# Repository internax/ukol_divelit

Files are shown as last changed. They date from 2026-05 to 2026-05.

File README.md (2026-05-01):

# SPI FLASH programátor
Tento repozitář obsahuje souboru k návrhu SPI Flash programátoru.

## Struktura
- Výrobní soubory jsou v adresáři: programator_spi/production/programator_spi.zip
- Schéma je dostupné v adresáři: programator_spi/schema_pdf/programator_spi.pdf
# Návrhová rozhodnutí

## Patice pro DIP8

Původní záměr byl použít ZIF socket, ten se však pro pDIP8 pouzdro prakticky nevyrábí. Zvolil jsem proto přesnou patici z doporučených komponent. Klíčovými kritérii byl nízký odpor kontaktů a zlaté pokovení pinů. Životnost patice je dle dokumentace přibližně 500 cyklů, což by pro daný účel mělo být dostatečné. Pokud by se požadavky na počet cyklů zvýšily, bylo by nutné přejít na ZIF patici většího formátu.

## USB rozhraní

Nejprve jsem navrhl USB rozhraní. Použil jsem ESD ochranu z doporučených komponent. Zvažoval jsem ještě ECMF02-2AMX6, která nabízí common mode ochranu a je použita například v referenčním designu MB1801.

Dále jsem přidal proudovou ochranu — polyfuse. Maximální proud jsem stanovil takto: flash paměť odebírá při zápisu až 30 mA, MCU pak dle datasheetu až 150 mA. Zvolil jsem proto polyfuse 200 mA, která poskytuje rozumnou rezervu; v případě potřeby ji lze snadno vyměnit.

Dle specifikace jsem na linku D+ přidal pull-up rezistor 1k5Ω.

## MCU

S STM32 jsem dosud nenavrhoval, proto jsem si stáhl AN a postupoval podle ní. Jako první jsem řešil napájení — přidal jsem blokovací kondenzátory na příslušné piny. Oddělení napájení analogové části jsem neřešil, protože zde nemá smysl.

Vybral jsem krystal 8 MHz tak, aby byl splněn margin, a navrhl jsem kondenzátory s tím, že Cp uvažuji jako 5 pF. Margin jsem ověřil dle AN2867 — vychází gm = 26,4 mA/V, rezerva je dostatečná.

## Programovací rozhraní

Pokračoval jsem programovacím rozhraním. Zvolil jsem SWD s výstupem SWO, konektor Tag-Connect.

## Tlačítka

Přidal jsem tlačítko RESET, protože je vhodné ho mít vždy vyvedené, a tlačítko BOOT pro změnu bootovacího režimu, například pro DFU přes USB. Tlačítko ERASE ani FLASH není zmíněno v zadání, takže jsem je nepřidával — zbytečná komplexita.

## Indikace

Pro indikaci stavu jsem zvolil adresovatelnou LED, která funguje s 5V logikou. Teoreticky by byl potřeba level shifter, nicméně v praxi funguje spolehlivě i bez něj, zejména na malých vzdálenostech.

## Flash

K napájení jsem přidal 100 nF kondenzátor, SPI jsem připojil k MCU, /WP a /HOLD jsem vyvedl na VDD, protože ani jednu z funkcí nepotřebuji. Na piny sdílené s MCU jsem přidal ESD ochranu.

## Test pady
Přidávám testpady s dírou uprostřed, protože v nich líp drží probe osciloskopu a ve dvouvrstvé desce ničemu nevadí.

*Text Návrhová rozhodnutí byl upravenu pomocí generativní umělé inteligence, originál je dostupný v: original_notes/notes.txt*

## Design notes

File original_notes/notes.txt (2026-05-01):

- Použiji doporučený čip s USB rozhraním, protože jej nativně podporuje
- Chtěl jsem použít ZFI socket,a le pro pDIP8 se moc nevyrábí takže použiju něco jiného s důrazem na to aby sto vyrželo opakované vysouvání a zasouvání čipů
- Existují přesné patice, které by tohle měly zaručit
- Vybírám patci ze zadání protože má nízký odpor kontaktů a zalté pokovení. Má životnost cca 500 cyklů [DIP IC Sockets](https://www.petervis.com/electronics/DIP_IC_Sockets/IC_Sockets.html) pokud by bylo potřeba víc musle by se použít větší ZIF
- Zbytek komponent jsem taky použil z doporučených
# USB
- Prvně navrhuji USB interface. Použiju ESD ze zadání. Pokud bych neměl doporučené komponenty,  bych zvažoval použití **ECMF02-2AMX6** která má common mode ochranu a je použita například v MB1801 u USB interface.
- Přidám produovou ochranu - polyfuse
	musím si určit max porud:
	- Paměť má největši spotřebu při zápisu - 30 mA
	- STM zvládne dle datasheetu 150 mA
	Takže polyfuse 200 mA by mohla být ok, kdyžtak se vymění
- dle specifikace přidávám 1k5 odpor na dp
# MCU
- S stm jsem nikdy nenavrhoval takže si stáhu AN a jedu podle ní. Jako první řeším napájení. 
	připojím decoupling kapacitory tam kam patří. odděelní napájení analogové části neřeším, protože to tady nemá cenu
- vybírám krystal na 8 MHz tak aby by splněn margin a navrhuji kondenzátory s tím že Cp beru jako 5pF
- Počítám si margin podle AN2867 a zjišťuji že je oka a mám dostatečnou rezervu gm=26,4 mA/V
# debug
- pokračuji, programovacím rozhraním. Volím rozhraní swo konektor tag connect
# Tlačítka
- potřebuji tlačítko pro reset, uvažuji nad tlačítkem erase a flash ale není zmíněno v zadání tak nebudu zbytečně přidávat komplexitu
- tlačítko reset přidávám protože je vhodné ho mít vyvedené a boot pro změnu bootovacího režimu např z usb
# Indikace
Pro indikaci stavu jsem vybral adresovatelnoou diodu, která funguje s 5V logikou, teoreticky by měl být level shifter, nicméně v praxi funguje dobře zeména na malé vzdálenosti i bez level shifteru.

# Flash
zbývá připojit flash paměť. k napájení přidám 100nF, připojím spi do čipu a WP a hold na vdd, protože ani jednu z funkcí nepotřebuji, přidám esd ochranu na piny které jsou spojeny s MCU

# Test pady
Přidávám testpady s dírou uprostřed, protože v nich líp drří probe osciloskopu a ve dvouvrstvé desce ničemu nevadí

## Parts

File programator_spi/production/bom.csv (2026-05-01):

Designator | Footprint | Quantity | Value | LCSC Part #
3V3, 5V, CS, MISO, MOSI, SCK | TestPoint_THTPad_D1.0mm_Drill0.5mm | 6 | TestPoint
C1, C4, C5 | 0603 | 3 | 10u
C10 | 0603 | 1 | 1u
C11, C12, C15, C2, C3, C6, C7, C8, C9 | 0603 | 9 | 100n
C13, C14 | 0603 | 2 | 27p
CR1 | SOT-223-3_TabPin2 | 1 | LD1117S33CTR
D1 | SOD2512X110N | 1 | D_Schottky
D2 | LED_WS2812B-Mini_PLCC4_3.5x3.5mm | 1 | WS2812B
F1 | 1206 | 1 | Polyfuse
H2, H3 | MountingHole_3.5mm | 2 | MountingHole
IC1 | DIP-8_W7.62mm_Socket | 1 | SST25VF080B-50-4C-PAE
J1 | USB4105_GCT | 1 | USB4105-GF-A
R1, R2 | 0603 | 2 | 5k1
R3, R4, R5 | 0603 | 3 | 10k
R7 | 0603 | 1 | 1k5
S1, S2 | TL3365AF250QG | 2 | TL3365AF180QG
U1 | LQFP48_STM-M | 1 | STM32F103C8T6
U2 | SOT-23-6 | 1 | USBLC6-4SC6
U3 | SOT-23-6 | 1 | USBLC6-2SC6
Y2 | LFXTAL055663Reel | 1 | 8MHz

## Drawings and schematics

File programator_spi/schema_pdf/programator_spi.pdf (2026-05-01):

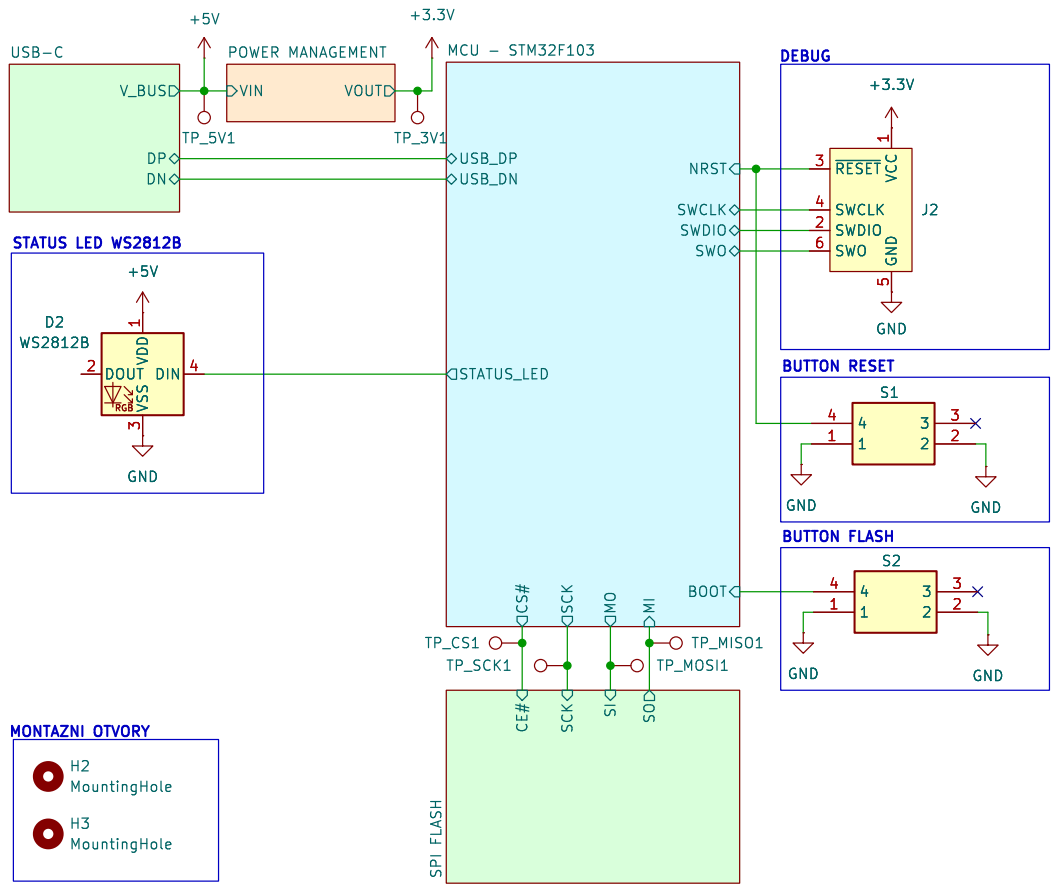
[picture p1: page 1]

5 ~{RESET} 3 SWCLK 4 SWDIO 2 SWO 6

5 ~{RESET} 3 SWCLK 4 SWDIO 2 SWO 6 GND

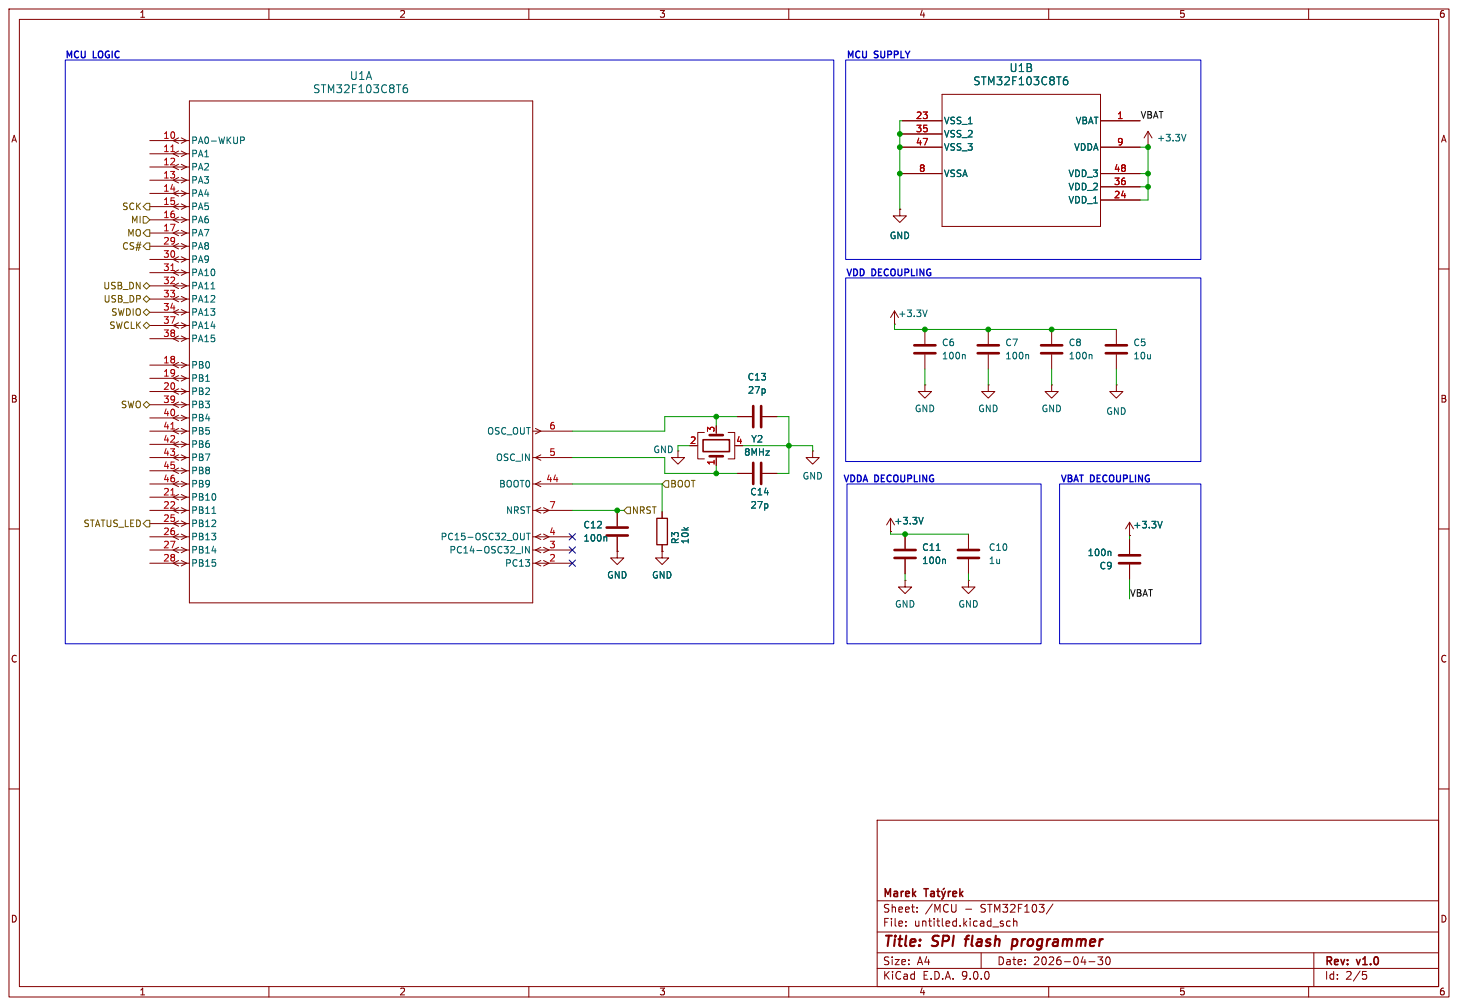
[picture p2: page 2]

CS# SCK MOMI SWO

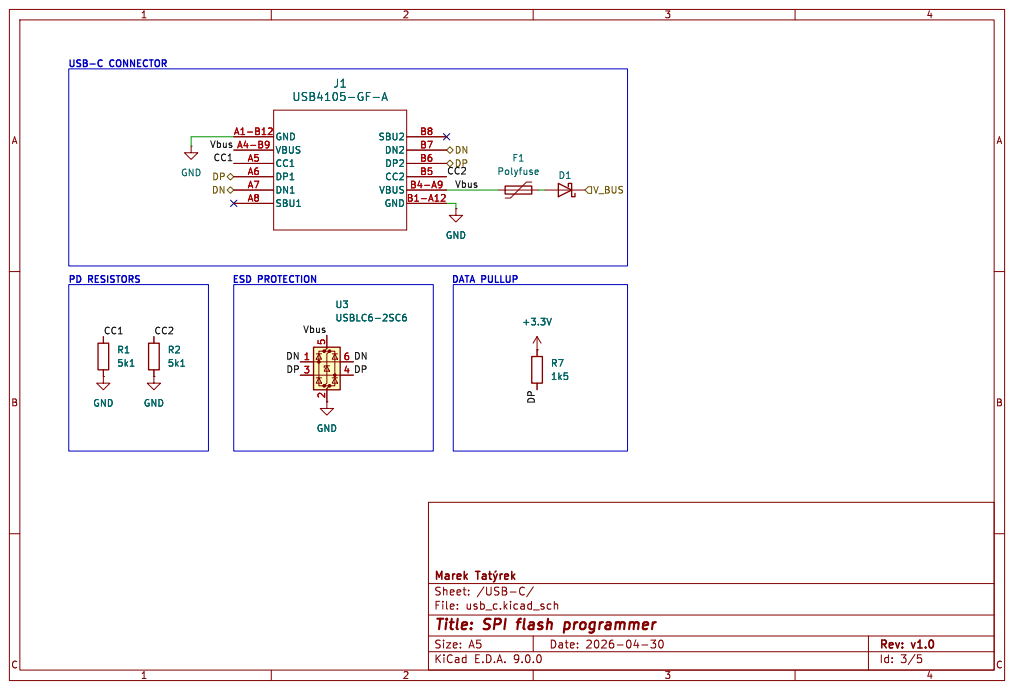
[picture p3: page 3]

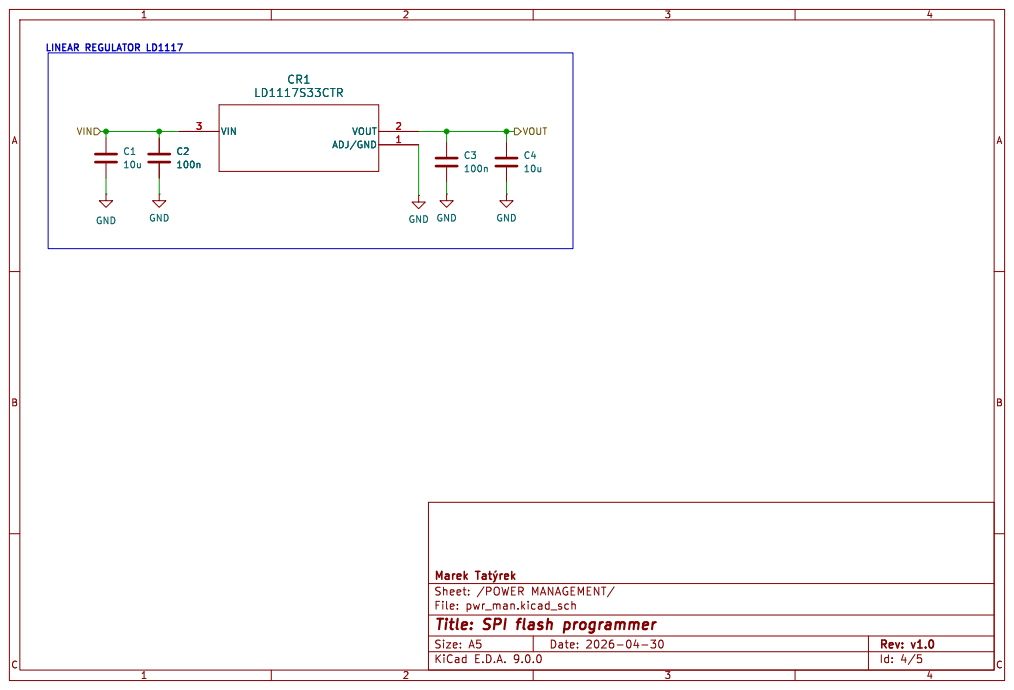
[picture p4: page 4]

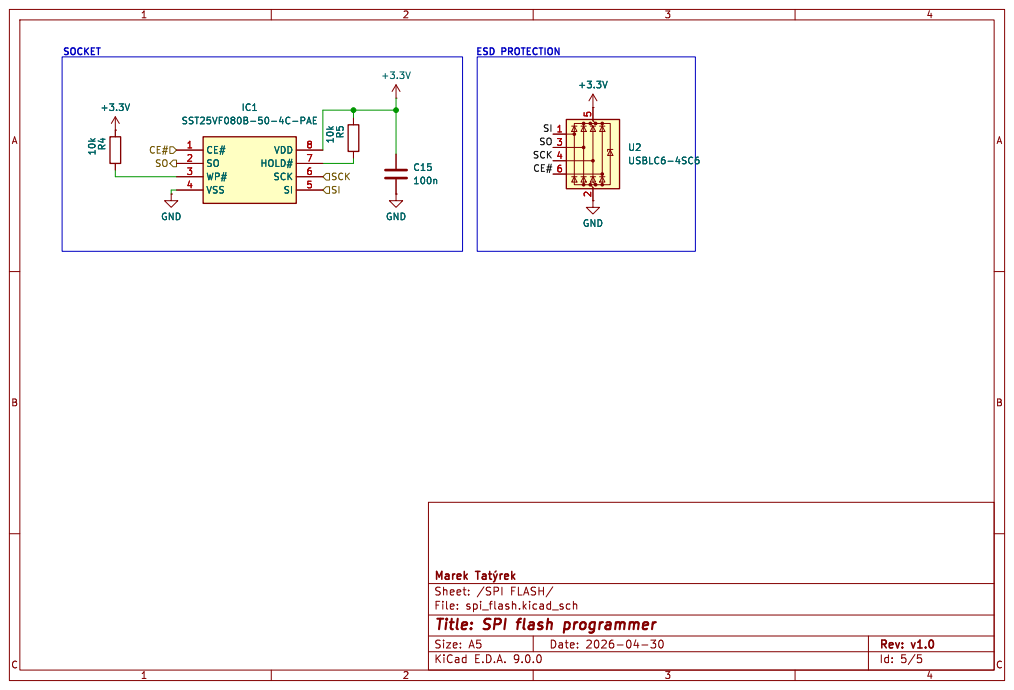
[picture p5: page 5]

5 2 U2 USBLC6-4SC6 CE# 1 SO 2 WP# 3 VSS 4 VDD 8 HOLD# 7 SCK 6 SI 5

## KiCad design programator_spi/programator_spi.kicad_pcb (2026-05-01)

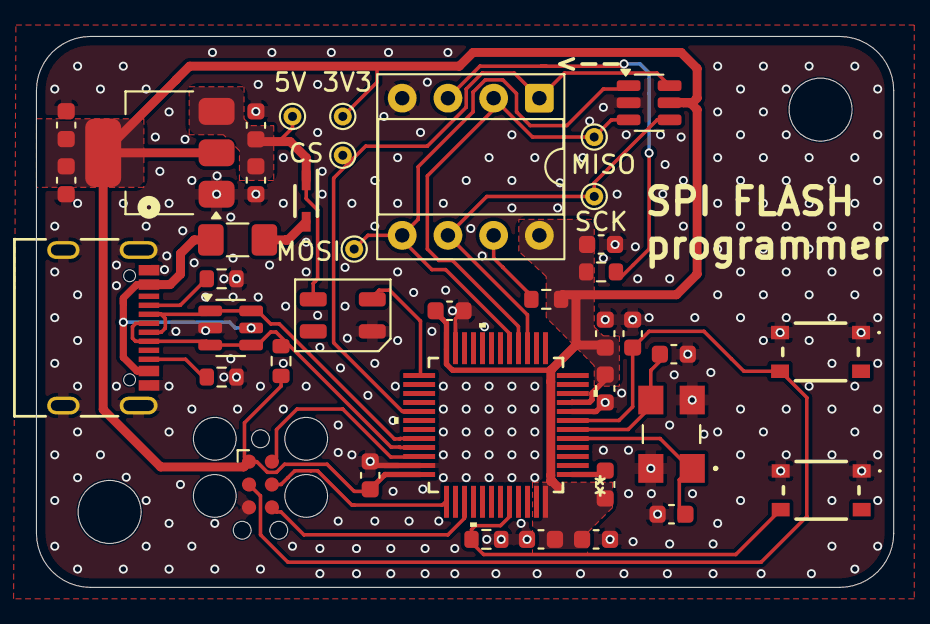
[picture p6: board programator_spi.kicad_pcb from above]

Board: 2 copper layers, 47.6 x 30.6 mm, 42 parts (0 on the bottom side), 24 nets.

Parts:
3V3, 5V: TestPoint; TestPoint_THTPad_D1.0mm_Drill0.5mm
C1, C4, C5: 10u; C_0603_1608Metric
C2, C3, C6, C7, C8, C9, C11, C12, C15: 100n; C_0603_1608Metric
C10: 1u; C_0603_1608Metric
C13, C14: 27p; C_0603_1608Metric
CR1: LD1117S33CTR; SOT-223-3_TabPin2
CS: TestPoint; TestPoint_THTPad_D1.0mm_Drill0.5mm
D1: D_Schottky; SOD2512X110N
D2: WS2812B; LED_WS2812B-Mini_PLCC4_3.5x3.5mm
F1: Polyfuse; Fuse_1206_3216Metric_Pad1.42x1.75mm_HandSolder
H2, H3: MountingHole; MountingHole_3.5mm
IC1: SST25VF080B-50-4C-PAE; DIP-8_W7.62mm_Socket
J1: USB4105-GF-A; USB4105_GCT
J2: Conn_ARM_SWD_TagConnect_TC2030; Tag-Connect_TC2030-IDC-FP_2x03_P1.27mm_Vertical
MISO: TestPoint; TestPoint_THTPad_D1.0mm_Drill0.5mm
MOSI: TestPoint; TestPoint_THTPad_D1.0mm_Drill0.5mm
R1, R2: 5k1; R_0603_1608Metric
R3, R4, R5: 10k; R_0603_1608Metric
R7: 1k5; R_0603_1608Metric
S1, S2: TL3365AF180QG; TL3365AF250QG
SCK: TestPoint; TestPoint_THTPad_D1.0mm_Drill0.5mm
U1: STM32F103C8T6; LQFP48_STM-M
U2: USBLC6-4SC6; SOT-23-6
U3: USBLC6-2SC6; SOT-23-6
Y2: 8MHz; LFXTAL055663Reel

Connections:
+3.3V: 3V3.1, C3.2, C4.2, C5.2, C6.2, C7.2, C8.2, C9.1, C10.1, C11.2, C15.2, CR1.2 (VOUT), IC1.8 (VDD), J2.1 (VCC), R4.2, R5.2, R7.1, U1.9 (VDDA), U1.24 (VDD_1), U1.36 (VDD_2), U1.48 (VDD_3), U2.5 (VBUS)
+5V: 5V.1, C1.2, C2.2, CR1.3 (VIN), D1.1 (K), D2.1 (VDD)
/MCU - STM32F103/BOOT: R3.1, S2.4, U1.44 (BOOT0)
/MCU - STM32F103/NRST: C12.2, J2.3 (~RESET), S1.4, U1.7 (NRST)
/MCU - STM32F103/STATUS_LED: D2.4 (DIN), U1.25 (PB12)
/MCU - STM32F103/SWCLK: J2.4 (SWCLK), U1.37 (PA14)
/MCU - STM32F103/SWDIO: J2.2 (SWDIO), U1.34 (PA13)
/MCU - STM32F103/SWO: J2.6 (SWO), U1.39 (PB3)
/MCU - STM32F103/VBAT: C9.2, U1.1 (VBAT)
/SPI FLASH/CE#: CS.1, IC1.1 (CE#), U1.29 (PA8), U2.6 (I/O4)
/SPI FLASH/SCK: IC1.6 (SCK), SCK.1, U1.15 (PA5), U2.4 (I/O3)
/SPI FLASH/SI: IC1.5 (SI), MOSI.1, U1.17 (PA7), U2.1 (I/O1)
/SPI FLASH/SO: IC1.2 (SO), MISO.1, U1.16 (PA6), U2.3 (I/O2)
/USB-C/CC1: J1.A5 (CC1), R1.1
/USB-C/CC2: J1.B5 (CC2), R2.1
/USB-C/DN: J1.A7 (DN1), J1.B7 (DN2), U1.32 (PA11), U3.1 (I/O1), U3.6 (I/O1)
/USB-C/DP: J1.A6 (DP1), J1.B6 (DP2), R7.2, U1.33 (PA12), U3.3 (I/O2), U3.4 (I/O2)
/USB-C/Vbus: F1.2, J1.A4-B9 (VBUS), J1.B4-A9 (VBUS), U3.5 (VBUS)
GND: C1.1, C2.1, C3.1, C4.1, C5.1, C6.1, C7.1, C8.1, C10.2, C11.1, C12.1, C13.2, C14.2, C15.1, CR1.1 (ADJ/GND), D2.3 (VSS), IC1.4 (VSS), J1.A1-B12 (GND), J1.B1-A12 (GND), J2.5 (GND), R1.2, R2.2, R3.2, S1.1, S1.2, S2.1, S2.2, U1.8 (VSSA), U1.23 (VSS_1), U1.35 (VSS_2), U1.47 (VSS_3), U2.2 (GND), U3.2 (GND), Y2.2, Y2.4
unnamed: D1.2 (A), F1.1
unnamed: IC1.7 (HOLD#), R5.1
unnamed: IC1.3 (WP#), R4.1
unnamed: C14.1, U1.5 (OSC_IN), Y2.1
unnamed: C13.1, U1.6 (OSC_OUT), Y2.3

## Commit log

2026-05-01 name change
    [mcu.kicad_sch, programator_spi.kicad_sch]
2026-05-01 Add README.md for SPI Flash programmer project
    Added detailed documentation for the SPI Flash programmer, including design decisions, structure, and components used.
2026-05-01 Add test pads to README for oscilloscope probes
    Added test pads with a hole in the center for better probe hold.
